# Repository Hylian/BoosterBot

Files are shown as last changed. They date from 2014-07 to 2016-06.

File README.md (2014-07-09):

BoosterBot
==========

A BoosterPack that turns your TI Launchpad into a fully functional robot!

The BoosterBot attaches underneath any 40-pin Launchpad to give it batteries, wheels, and access to a bunch of sensors; perfect for anyone who wants to get started with MSP430 and robotics, or just wants an easy to use robotics platform to build off of.

Features
--------
* Micro Metal Gearmotors from Pololu
* Powered by 3xAAA batteries
* Five QRE1113 Reflectance sensors for line following and maze solving
* Header for a Sharp IR distance sensor
* Header for a servo
* Compatible with other BoosterPacks, including the FuelTank battery BoosterPack

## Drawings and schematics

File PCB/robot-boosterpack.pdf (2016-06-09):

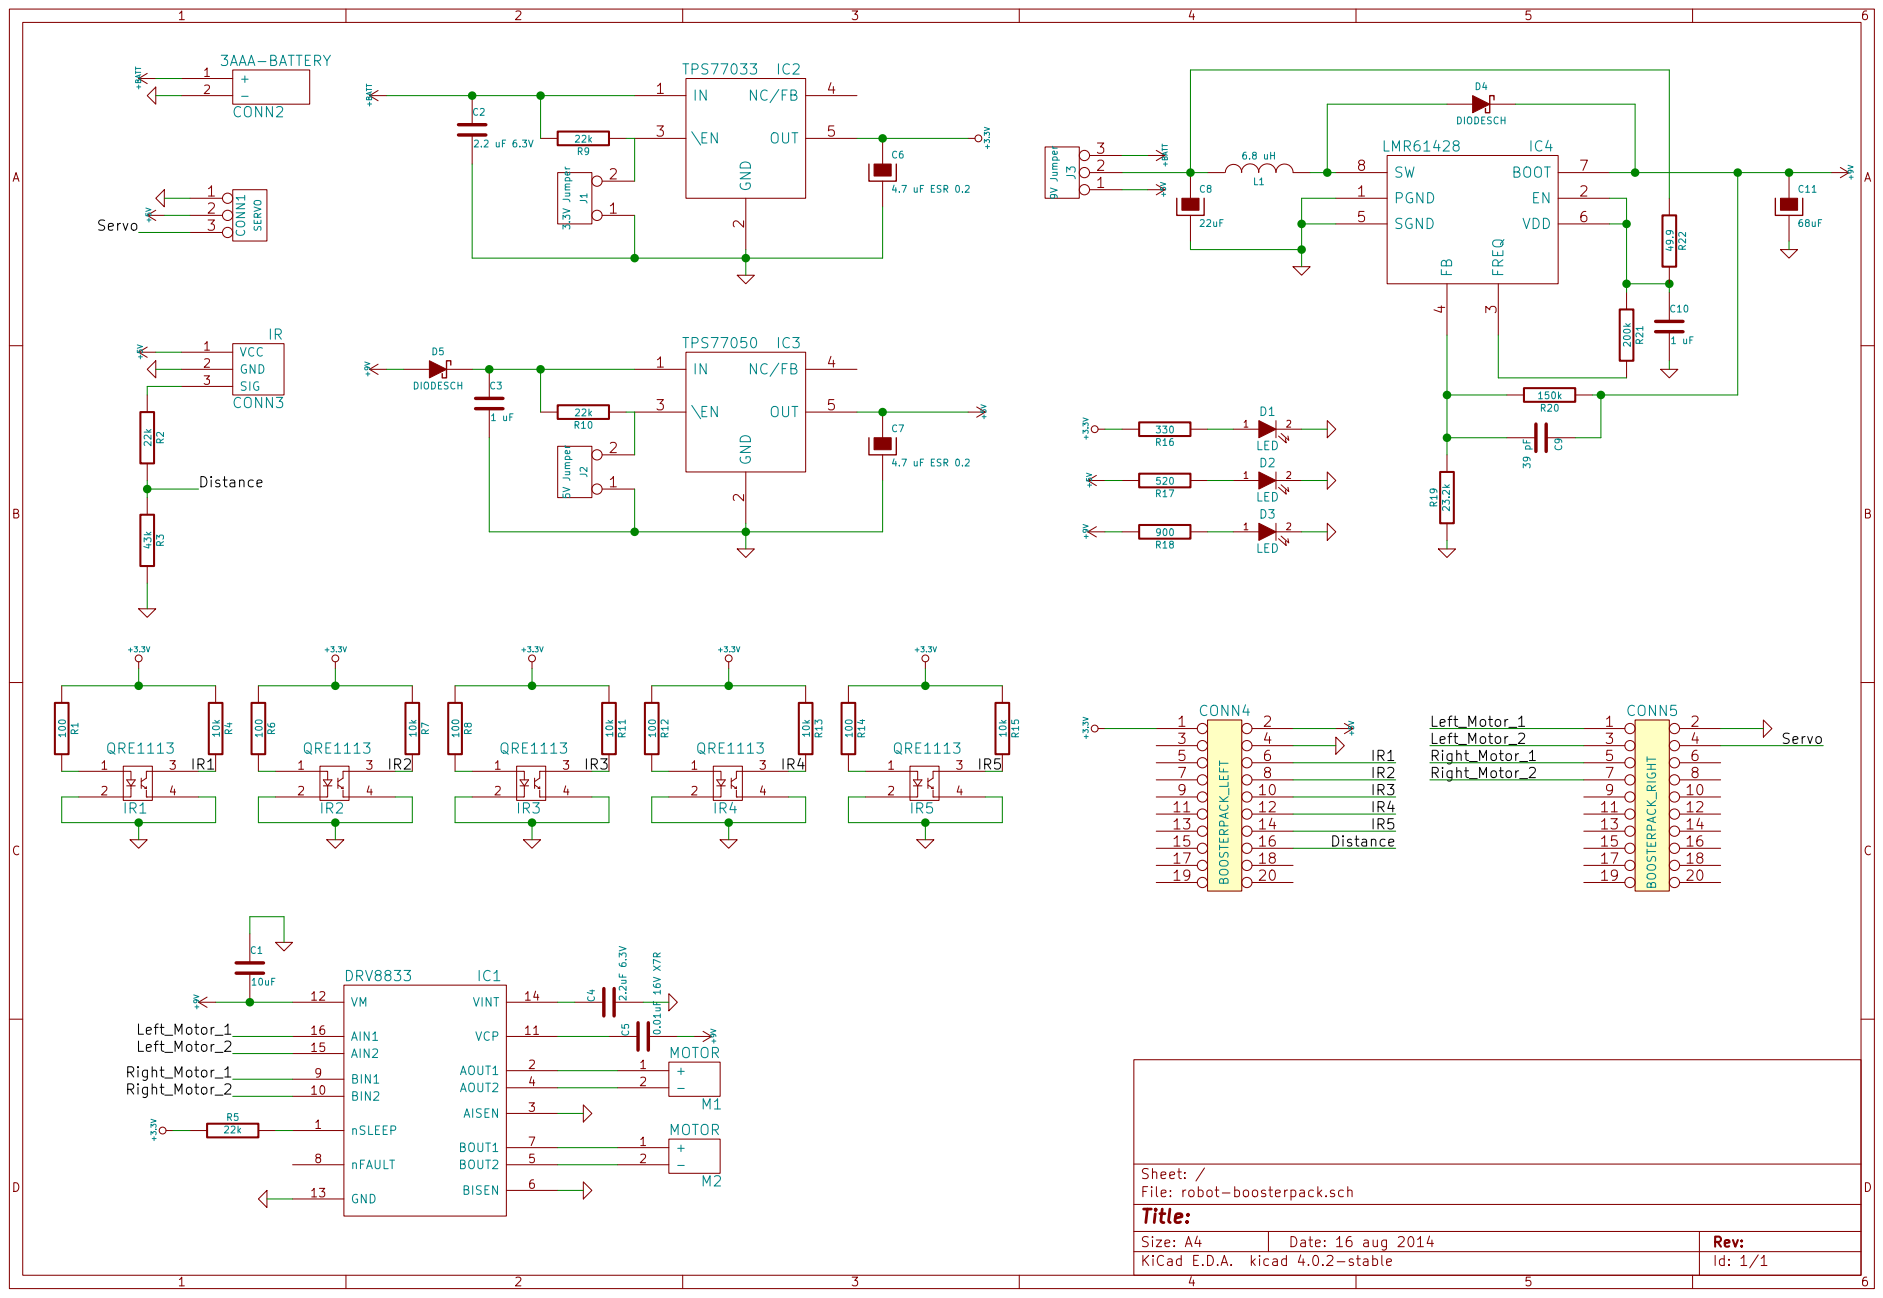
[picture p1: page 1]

4 SGND 5 VDD 6 BOOT 7 SW 8

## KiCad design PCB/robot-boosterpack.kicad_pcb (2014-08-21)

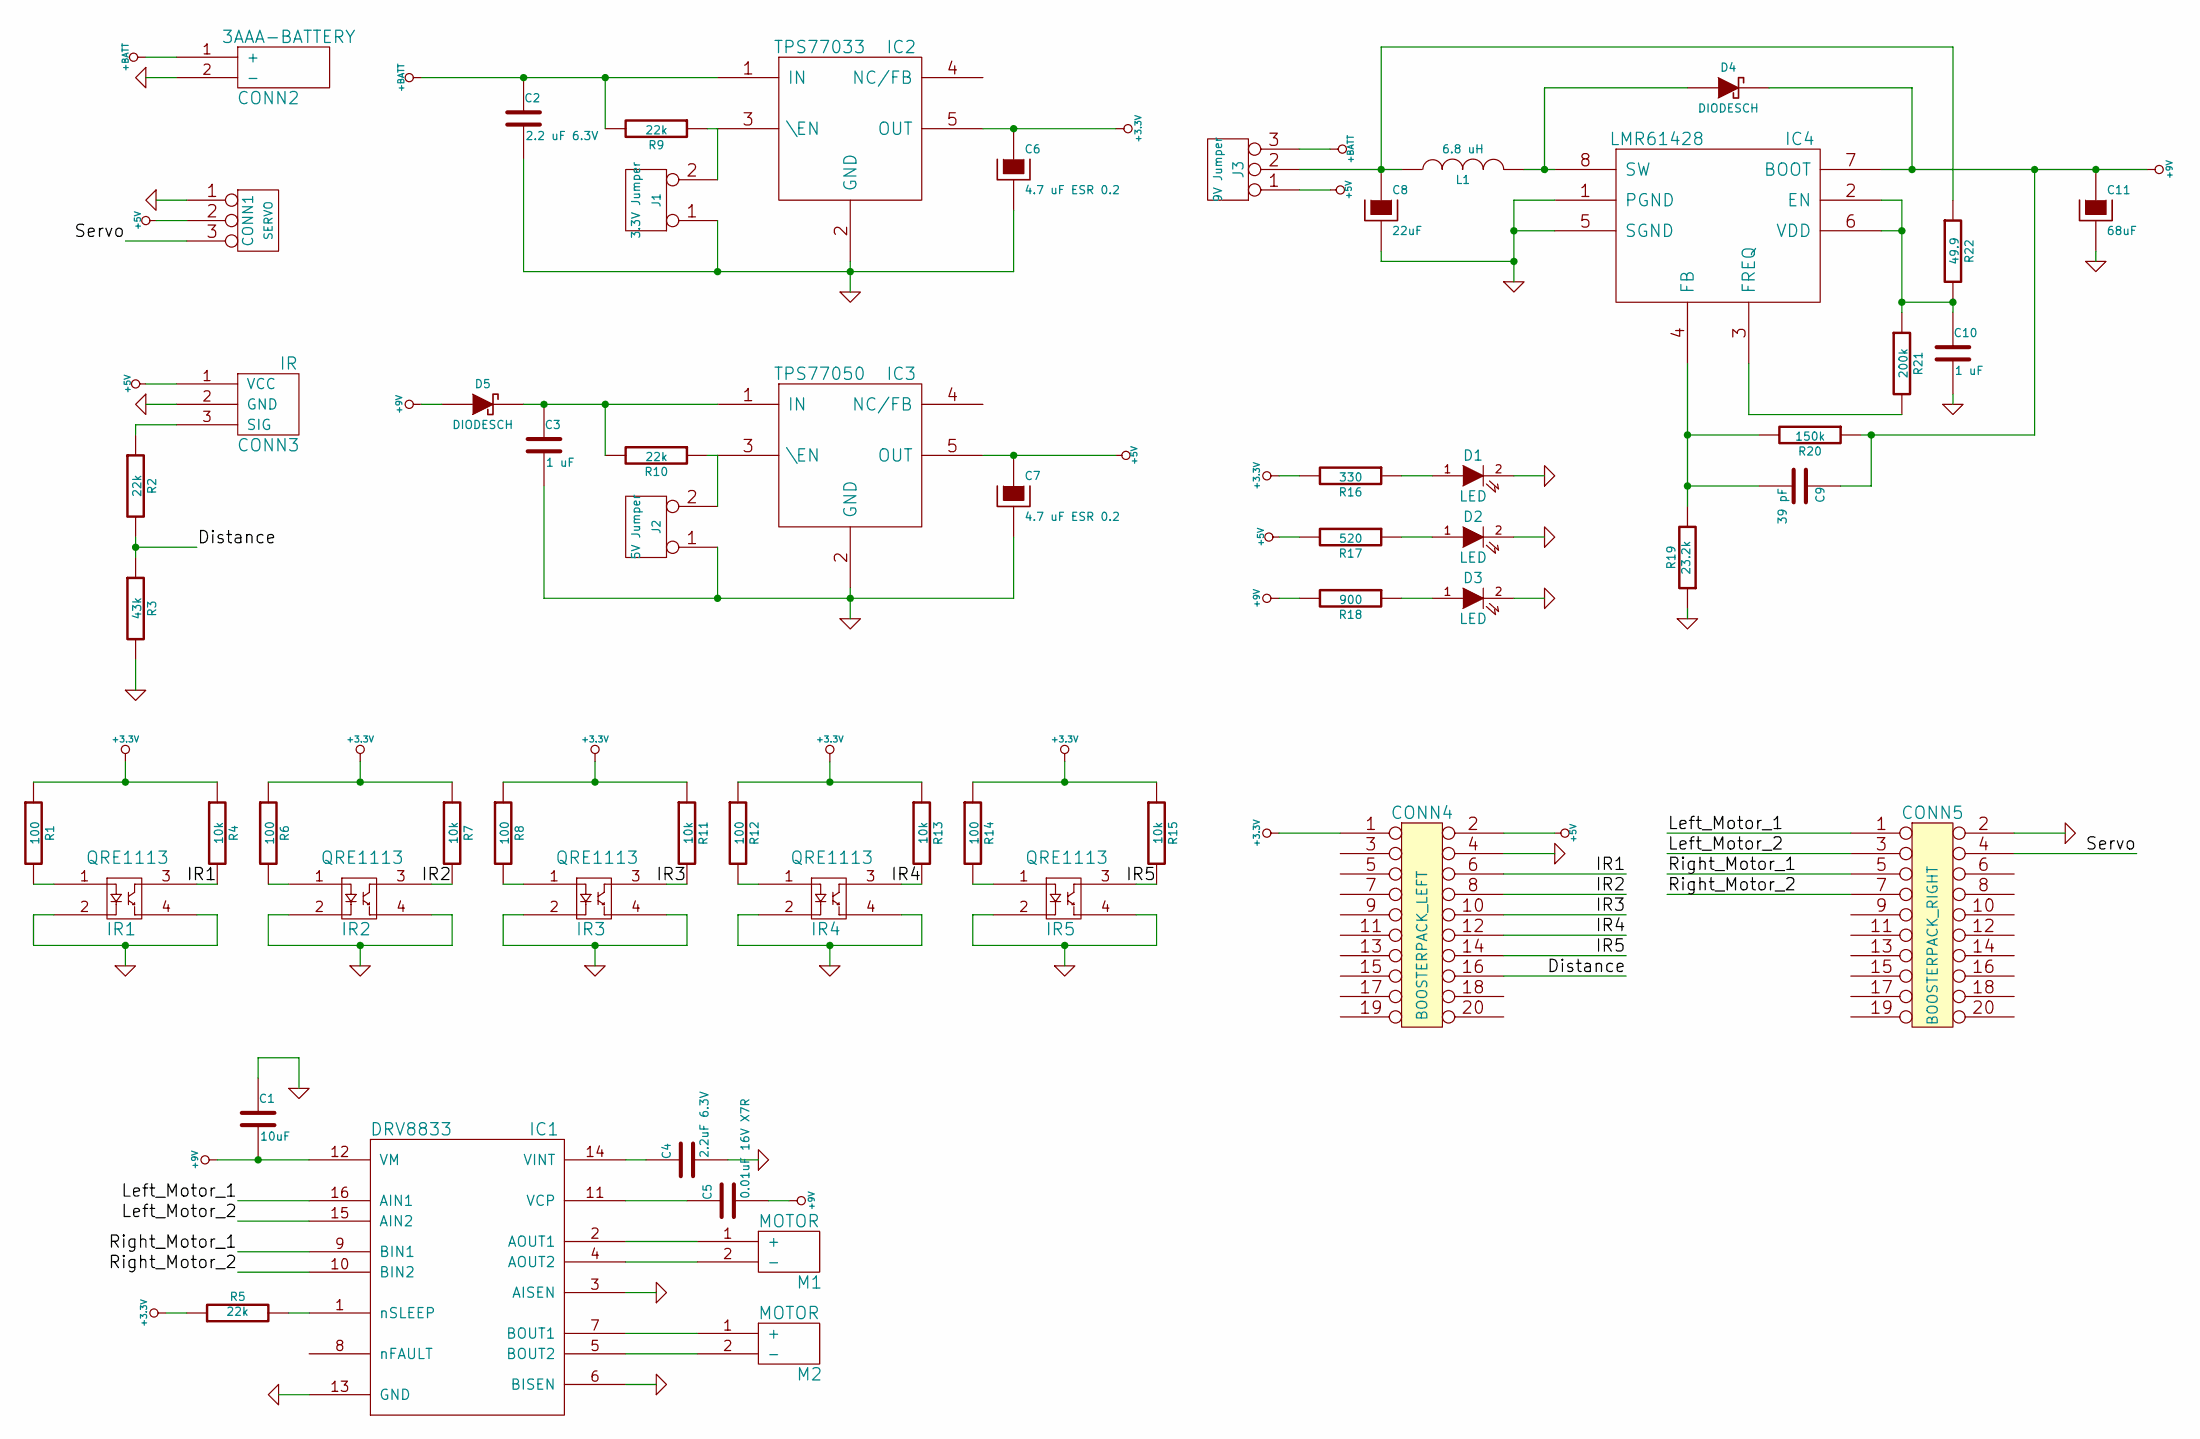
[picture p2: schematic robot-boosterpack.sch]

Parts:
C1: 10uF; Digikey # 311-1343-1-ND
C2: 2.2 uF 6.3V; Digikey # 587-1254-1-ND
C3, C10: 1 uF; Digikey # 587-1242-1-ND
C4: 2.2uF 6.3V; Digikey # 587-1254-1-ND
C5: 0.01uF 16V X7R; Digikey # 490-1512-1-ND
C6, C7: 4.7 uF ESR 0.2; Digikey # 478-1772-1-ND
C8: 22uF; Digikey # 399-3716-1-ND
C9: 39 pF
C11: 68uF; Digikey # 399-4698-1-ND
CONN1: SERVO; Digikey # 609-3461-ND
CONN2: 3AAA-BATTERY
CONN3: IR; Digikey # S5751-03-ND
CONN4: BOOSTERPACK_LEFT
CONN5: BOOSTERPACK_RIGHT
D1: LED; Digikey # 160-1448-1-ND
D2: LED; Digikey # 160-1447-1-ND
D3: LED; Digikey # 160-1647-1-ND
D4, D5: DIODESCH; Digikey # MBRS140T3GOSCT-ND
IC1: DRV8833
IC2: TPS77033
IC3: TPS77050
IC4: LMR61428
IR1, IR2, IR3, IR4, IR5: QRE1113
J1: 3.3V Jumper; Digikey # 3M9447-ND
J2: 5V Jumper; Digikey # 3M9447-ND
J3: 9V Jumper; Digikey # 609-3461-ND
L1: 6.8 uH; Digikey # SRN6045-100MCT-ND
M1, M2: MOTOR
R1, R6, R8, R12, R14: 100; Digikey # 311-100HRCT-ND
R2, R5, R9, R10: 22k; Digikey # P22KDBTR-ND
R3: 43k; Digikey # 311-43.0KHRCT-ND
R4, R7, R11, R13, R15: 10k; Digikey # 311-10KGRCT-ND
R16: 330; Digikey # 311-165HRCT-ND
R17: 520; Digikey # P261HCT-ND
R18: 900; Digikey # P453HCT-ND
R19: 23.2k; Digikey # 311-23.2KHRTR-ND
R20: 150k; Digikey # P150KDBCT-ND
R21: 200k; Digikey # P200KDBCT-ND
R22: 49.9; Digikey # P49.9HCT-ND

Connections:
+3.3V: C6.1, CONN4.1, IC2.5 (OUT), R1.1, R4.1, R5.1, R6.1, R7.1, R8.1, R11.1, R12.1, R13.1, R14.1, R15.1, R16.2
+5V: C7.1, CONN1.2 (PM), CONN3.1 (VCC), CONN4.2, IC3.5 (OUT), J3.1, R17.2
+9V: C1.2, C5.2, C9.1, C11.1, D4.2 (K), D5.1 (A), IC1.12 (VM), IC4.7 (BOOT), R18.2, R20.1
+BATT: C2.1, CONN2.1 (+), IC2.1 (IN), J3.3, R9.2
/Distance: CONN4.16, R2.2, R3.1
/IR1: CONN4.6, IR1.3, R4.2
/IR2: CONN4.8, IR2.3, R7.2
/IR3: CONN4.10, IR3.3, R11.2
/IR4: CONN4.12, IR4.3, R13.2
/IR5: CONN4.14, IR5.3, R15.2
/Left_Motor_1: CONN5.1, IC1.16 (AIN1)
/Left_Motor_2: CONN5.3, IC1.15 (AIN2)
/Right_Motor_1: CONN5.5, IC1.9 (BIN1)
/Right_Motor_2: CONN5.7, IC1.10 (BIN2)
/Servo: CONN1.3, CONN5.4
GND: C1.1, C2.2, C3.2, C4.2, C6.2, C7.2, C8.2, C10.2, C11.2, CONN1.1, CONN2.2 (-), CONN3.2 (GND), CONN4.4, CONN5.2, D1.2 (K), D2.2 (K), D3.2 (K), IC1.3 (AISEN), IC1.6 (BISEN), IC1.13 (GND), IC2.2 (GND), IC3.2 (GND), IC4.1 (PGND), IC4.5 (SGND), IR1.2, IR1.4, IR2.2, IR2.4, IR3.2, IR3.4, IR4.2, IR4.4, IR5.2, IR5.4, J1.1, J2.1, R3.2, R19.1
unnamed: C9.2, IC4.4 (FB), R19.2, R20.2
unnamed: IC4.3 (FREQ), R21.2
unnamed: IR4.1, R12.2
unnamed: C10.1, IC4.2 (EN), IC4.6 (VDD), R21.1, R22.2
unnamed: IR3.1, R8.2
unnamed: IR2.1, R6.2
unnamed: C4.1, IC1.14 (VINT)
unnamed: C5.1, IC1.11 (VCP)
unnamed: IC1.1 (nSLEEP), R5.2
unnamed: IR1.1, R1.2
unnamed: CONN3.3 (SIG), R2.1
unnamed: D4.1 (A), IC4.8 (SW), L1.2
unnamed: D3.1 (A), R18.1
unnamed: D2.1 (A), R17.1
unnamed: D1.1 (A), R16.1
unnamed: C8.1, J3.2 (PM), L1.1, R22.1
unnamed: IC3.3 (\EN), J2.2 (PM), R10.1
unnamed: IR5.1, R14.2
unnamed: IC2.3 (\EN), J1.2 (PM), R9.1
unnamed: IC1.7 (BOUT1), M2.1 (+)
unnamed: IC1.5 (BOUT2), M2.2 (-)
unnamed: IC1.4 (AOUT2), M1.2 (-)
unnamed: IC1.2 (AOUT1), M1.1 (+)
unnamed: C3.1, D5.2 (K), IC3.1 (IN), R10.2

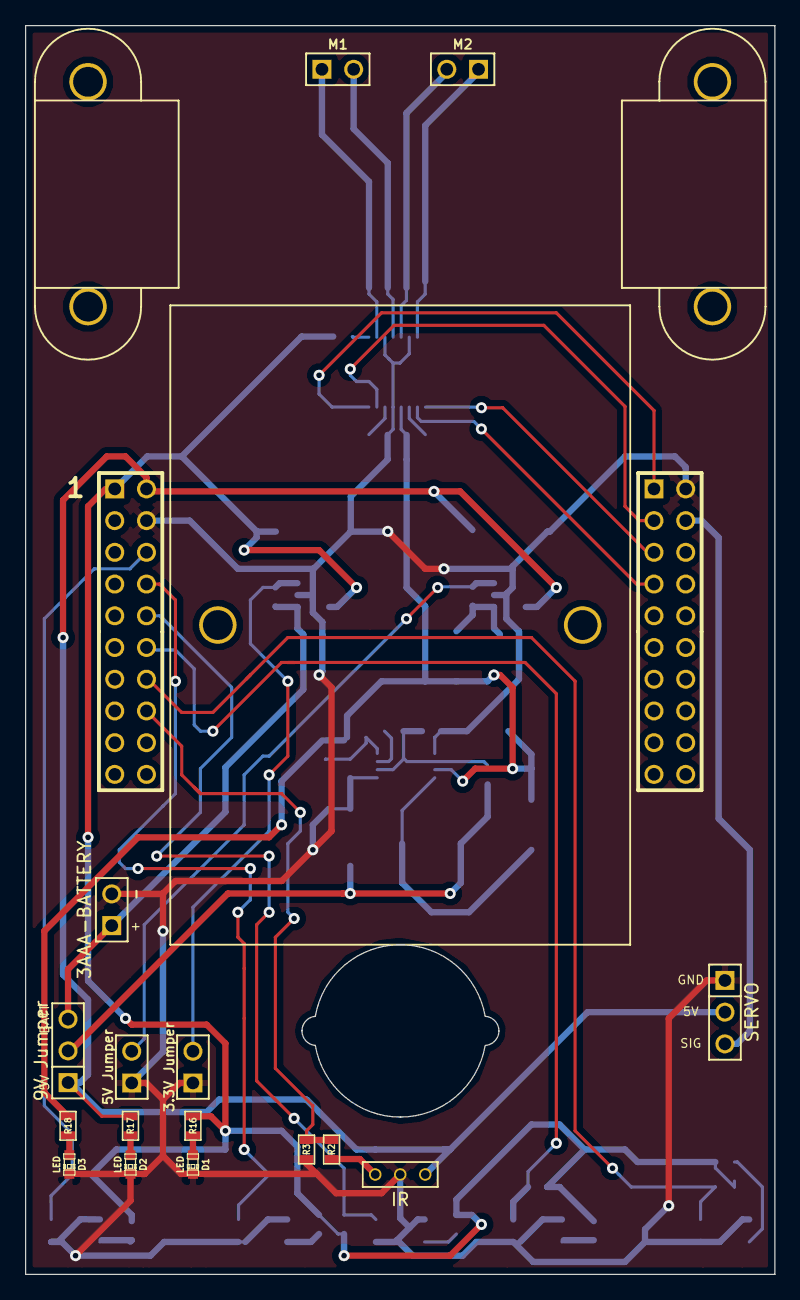
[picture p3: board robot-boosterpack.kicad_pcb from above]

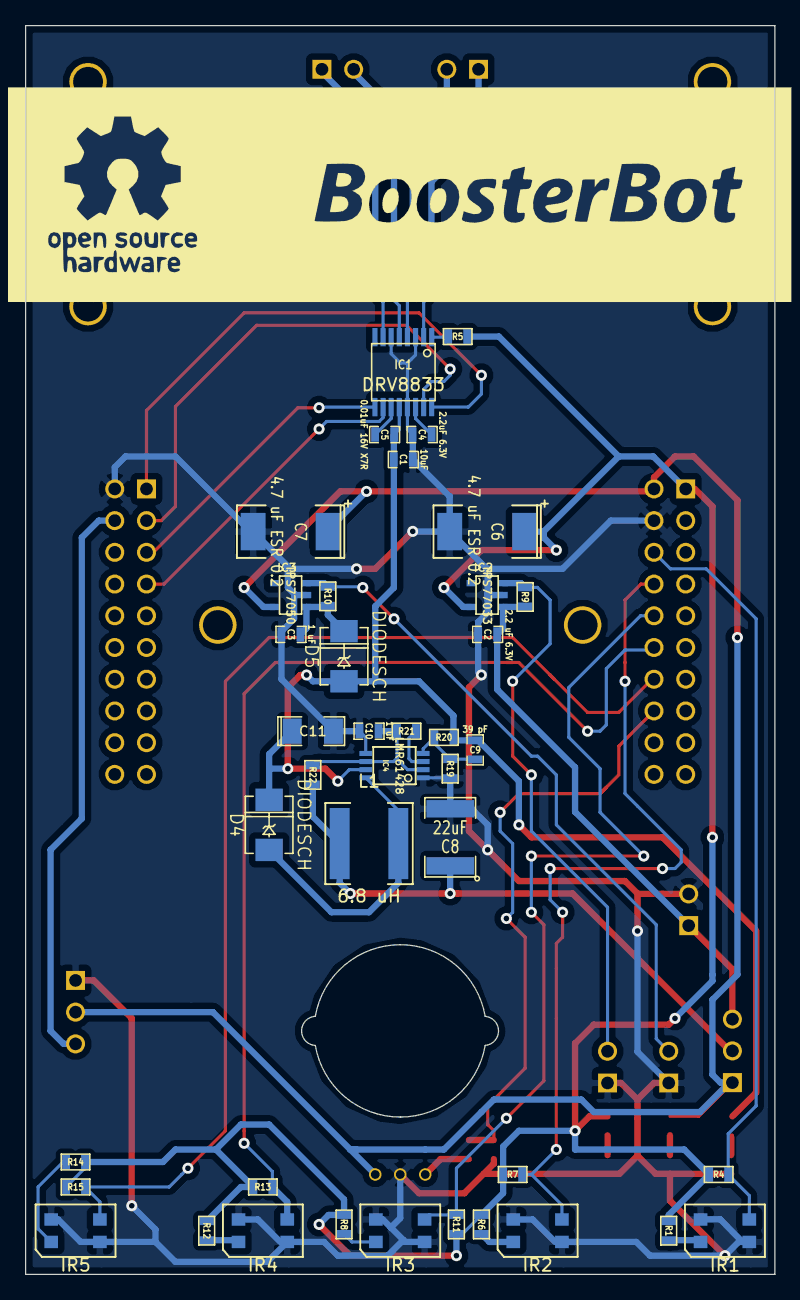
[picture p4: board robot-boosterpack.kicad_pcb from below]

Board: 2 copper layers, 60.0 x 100.0 mm, 61 parts (40 on the bottom side), 40 nets.

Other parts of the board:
BATTERY: P***; 3xAAA
GEARMOTOR: P***; 1pin
GEARMOTOR#2: P***; 1pin

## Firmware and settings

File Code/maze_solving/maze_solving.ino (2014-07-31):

#include "Motor.h"
#include "PID_v1.h"

double Setpoint, Input, Output;

bool sensorBool[5];
bool prevLeft, prevRight;
uint32_t threshold;

const uint8_t sensorPin[5] = {23, 24, 25, 26, 27};

const uint8_t baseSpeed = 100;
const uint8_t turnSpeed = 30;

PID linePID(&Input, &Output, &Setpoint, 40, 5, 1, DIRECT);

Motor leftMotor(37, 38, true);
Motor rightMotor(40, 39, true);

enum mazeState {STOP, FOLLOW, TURN_LEFT, TURN_RIGHT, DONE};

void calibrate()
{
	threshold = 0;
	for(char i = 0; i < 5; i++)
		threshold += analogRead(sensorPin[i]);
	threshold /= 5;
	threshold += 10;
        Serial.print("Threshold set: ");
        Serial.println(threshold);
}

void readSensors()
{
	for(char i = 0; i < 5; i++)
		sensorBool[i] = (analogRead(sensorPin[i]) < threshold);
}

void calculateError()
{
	if(sensorBool[1] && !sensorBool[2] && !sensorBool[3])
		Input = 2.0;
	else if(sensorBool[1] && sensorBool[2] && !sensorBool[3])
		Input = 1.0;
	else if(	(sensorBool[1] && sensorBool[2] && sensorBool[3]) ||
				(!sensorBool[1] && sensorBool[2] && !sensorBool[3]) 
	  		)
	  	Input = 0.0;
	else if(!sensorBool[1] && sensorBool[2] && sensorBool[3])
		Input = -1.0;
	else if(!sensorBool[1] && !sensorBool[2] && sensorBool[3])
		Input = -2.0;
	else
		Input = 0.0;

        Serial.print("Error: ");
        Serial.println(Input);
}

void setup()
{
        Serial.begin(9600);
        mazeState state = STOP;
	Input = 0;
	Setpoint = 0;
	linePID.SetMode(MANUAL);
	linePID.SetOutputLimits(-100, 100);
        leftMotor.setVelocity(speed);
	rightMotor.setVelocity(speed);  
        calibrate();
}

void loop()
{
	switch(state)
	{
		case STOP:
			linePID.SetMode(MANUAL);
			leftMotor.setSpeed(0);
			rightMotor.setSpeed(0);
			break;

		case FOLLOW:
			linePID.SetMode(AUTOMATIC);
			while(!sensorBool[0] || !sensorBool[4] || (!sensorBool[1]&&!sensorBool[2]&&!sensorBool[3]))
			{
				readSensors();
				calculateError();
				linePID.Compute();
				leftMotor.setSpeed(baseSpeed + Output);
				rightMotor.setSpeed(baseSpeed - Output);
			}
			prevLeft = sensorBool[0];
			prevRight = sensorBool[4];
			delay(400);
			readSensors();
			if(sensorBool[0]&&sensorBool[1]&&sensorBool[2]&&sensorBool[3]&&sensorBool[4])
				state = DONE;
			else if(prevLeft)
				state = TURN_LEFT;
			else
				state = TURN_RIGHT;
			break;

		case TURN_LEFT:
			linePID.SetMode(MANUAL);
			leftMotor.setSpeed(baseSpeed - turnSpeed);
			rightMotor.setSpeed(baseSpeed + turnSpeed);
			do
			{
				readSensors();
			}
			while(sensorBool[2]);
			do
			{
				readSensors();
			}
			while(!sensorBool[2]);
			state = FOLLOW;
			break;

		case TURN_RIGHT:
			linePID.SetMode(MANUAL);
			leftMotor.setSpeed(baseSpeed + turnSpeed);
			rightMotor.setSpeed(baseSpeed - turnSpeed);
			do
			{
				readSensors();
			}
			while(sensorBool[2]);
			do
			{
				readSensors();
			}
			while(!sensorBool[2]);
			state = FOLLOW;
			break;

		case DONE:
			linePID.SetMode(MANUAL);
			leftMotor.setSpeed(0);
			leftMotor.setSpeed(0);
			for(;;) {}
	}


	delay(50);
}

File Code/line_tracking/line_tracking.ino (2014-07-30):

#include "Motor.h"
#include "PID_v1.h"
#include "RunningAverage.h"

double Setpoint, prevInput, Input, Output;

bool sensorBool[5];
bool lostInput;
uint32_t threshold[5];
uint32_t maxValues[5], minValues[5], avgValues[5];
uint32_t tempValue;

const uint8_t sensorPin[5] = {23, 24, 25, 26, 27};

const uint8_t speed = 45;

PID linePID(&Input, &Output, &Setpoint, 5, 0, 0, DIRECT);

RunningAverage RA0(30);
RunningAverage RA1(30);
RunningAverage RA2(30);
RunningAverage RA3(30);
RunningAverage RA4(30);

Motor leftMotor(37, 38, true);
Motor rightMotor(40, 39, true);

void calibrate()
{
        while(digitalRead(P1_1)){}
        while(!digitalRead(P1_1)){}
        
        for(char i = 0; i < 5; i++)
        {
          minValues[i] = 0;
          maxValues[i] = 0;
        }        
        
        delay(500);
        
        Serial.println("Starting calibration");
        
        for(char i = 0; i < 5; i++)
        {
          minValues[i] = analogRead(sensorPin[i]);
          maxValues[i] = minValues[i];
        }
        
        while(digitalRead(P1_1))
        {
          for(char i = 0; i < 5; i++)
          {
            tempValue = analogRead(sensorPin[i]);
            if(tempValue < minValues[i])
              minValues[i] = tempValue;
            if(tempValue > maxValues[i])
              maxValues[i] = tempValue;
            Serial.print(tempValue);
            Serial.print(" ");
          }
          Serial.println();
        }
        
        for(char i = 0; i < 5; i++)
        {
          avgValues[i] = (2*minValues[i] + 3*maxValues[i])/5;
        }
        
        Serial.println("Calibration complete!");
            
        for(char i = 0; i < 5; i++)
          {
          Serial.println(avgValues[i]);        
          }
        /**
        for(char i = 0; i < 5; i++)
		threshold[i] = 0;
        for(char j = 0; j < 5; j++)
        {
            for(char i = 0; i < 5; i++)
		threshold[i] += analogRead(sensorPin[i]);
        }
        for(char i = 0; i < 5; i++)
        {
                threshold[i] /= 5;
                threshold[i] -= 400;
        }
        
        threshold[1] -= 500;
        threshold[2] -= 500;
	
        Serial.print("Threshold set: ");
        Serial.print(threshold[0]);
        Serial.print(" ");
        Serial.print(threshold[1]);
        Serial.print(" ");
        Serial.print(threshold[2]);
        Serial.print(" ");
        Serial.print(threshold[3]);
        Serial.print(" ");
        Serial.println(threshold[4]);
        
        */

}

void calibrate2()
{
  while(digitalRead(P1_1)){}
  while(!digitalRead(P1_1)){}
  
  Serial.println("Starting white calibration...");
  
  RA0.clear();
  RA1.clear();
  RA2.clear();
  RA3.clear();
  RA4.clear();
  
  while(digitalRead(P1_1))
  {
    RA0.addValue(analogRead(sensorPin[0]));
    RA1.addValue(analogRead(sensorPin[1]));
    RA2.addValue(analogRead(sensorPin[2]));
    RA3.addValue(analogRead(sensorPin[3]));
    RA4.addValue(analogRead(sensorPin[4]));
    Serial.println("averaging whites...");
  }

  minValues[0] = RA0.getAverage();
  minValues[1] = RA1.getAverage();
  minValues[2] = RA2.getAverage();
  minValues[3] = RA3.getAverage();
  minValues[4] = RA4.getAverage();
  
  while(!digitalRead(P1_1));
  
  delay(100);

  Serial.println("Starting black calibration...");

  RA0.clear();
  RA1.clear();
  RA2.clear();
  RA3.clear();
  RA4.clear();
  
  while(digitalRead(P1_1))
  {
    RA0.addValue(analogRead(sensorPin[0]));
    RA1.addValue(analogRead(sensorPin[1]));
    RA2.addValue(analogRead(sensorPin[2]));
    RA3.addValue(analogRead(sensorPin[3]));
    RA4.addValue(analogRead(sensorPin[4]));
        Serial.println("averaging blacks...");
  }

  maxValues[0] = RA0.getAverage();
  maxValues[1] = RA1.getAverage();
  maxValues[2] = RA2.getAverage();
  maxValues[3] = RA3.getAverage();
  maxValues[4] = RA4.getAverage();
  
  avgValues[0] = (2 * minValues[0] + 3 * maxValues[0])/5;
  avgValues[1] = (2 * minValues[1] + 3 * maxValues[1])/5;
  avgValues[2] = (2 * minValues[2] + 3 * maxValues[2])/5;
  avgValues[3] = (2 * minValues[3] + 3 * maxValues[3])/5;
  avgValues[4] = (2 * minValues[4] + 3 * maxValues[4])/5;
  
          Serial.println("Calibration complete!");
            
        for(char i = 0; i < 5; i++)
          {
          Serial.println(avgValues[i]);        
          }
}  
  

void readSensors()
{
  for(char i = 0; i < 5; i++)
  {
    sensorBool[i] = analogRead(sensorPin[i]) >   avgValues[i];
  }
}

void calculateError()
{
	if(sensorBool[1] && !sensorBool[2] && !sensorBool[3])
		Input = 2.0;
	else if(sensorBool[1] && sensorBool[2] && !sensorBool[3])
		Input = 1.0;
	else if(	(sensorBool[1] && sensorBool[2] && sensorBool[3]) ||
			(!sensorBool[1] && sensorBool[2] && !sensorBool[3]) 
	  		)
	  	Input = 0.0;
	else if(!sensorBool[1] && sensorBool[2] && sensorBool[3])
		Input = -1.0;
	else if(!sensorBool[1] && !sensorBool[2] && sensorBool[3])
		Input = -2.0;
	else if(!lostInput)
        {
          Input = -prevInput;
          lostInput = true;
          return;
        }
        else
          return;
        lostInput = false;
                 
        prevInput = Input;
        //Serial.print("Error: ");
        //Serial.println(Input);
}

void setup()
{
        pinMode(P1_1, INPUT_PULLUP);
        Serial.begin(9600);
	Input = 0;
        prevInput = 0;
	Setpoint = 0;
        leftMotor.setVelocity(0);
	rightMotor.setVelocity(0);
        calibrate();
	linePID.SetMode(AUTOMATIC);
	linePID.SetOutputLimits(-100, 100);
        leftMotor.setVelocity(speed);
	rightMotor.setVelocity(speed);

}

void loop()
{
	readSensors();
	calculateError();
	linePID.Compute();
	//leftMotor.setVelocity(speed - Output);
	//rightMotor.setVelocity(speed + Output);
	leftMotor.setVelocity(0);
	rightMotor.setVelocity(0);
        //Serial.print("Output: ");
        //Serial.println(Output);
        Serial.print("Reading: ");
        Serial.print(sensorBool[0]);
        Serial.print(" ");
        Serial.print(sensorBool[1]);
        Serial.print(" ");
        Serial.print(sensorBool[2]);
        Serial.print(" ");
        Serial.print(sensorBool[3]);
        Serial.print(" ");
        Serial.println(sensorBool[4]);
        //Serial.print("Raw Input: ");
        //Serial.print(analogRead(sensorPin[1]));
        //Serial.print(" ");
        //Serial.print(analogRead(sensorPin[2]));
        //Serial.print(" ");
        //Serial.println(analogRead(sensorPin[3]));
}

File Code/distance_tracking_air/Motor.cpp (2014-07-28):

/*
 * Motor.cpp
 * Controls a single motor connected to a DRV8833 motor driver via PWM.
 * Created by Edward Shin, 11 July 2014.
 */

#include "Energia.h"
#include "Motor.h"


Motor::Motor(uint16_t forwardPin, uint16_t reversePin, bool hardBrake)
{
	_forwardPin = forwardPin;
	_reversePin = reversePin;
	_hardBrake = hardBrake;
	_pin = _forwardPin;
	_speed = 0;
	_direction = FORWARD;

	pinMode(_forwardPin, OUTPUT);
	pinMode(_reversePin, OUTPUT);
}

void Motor::setSpeed(uint8_t speed)
{
	_speed = speed;
	analogWrite(_pin, _speed);

	if(_speed = 0)
	{
		if(_pin == _forwardPin)
			analogWrite(_reversePin, _hardBrake ? 255 : 0);
		else
			analogWrite(_forwardPin, _hardBrake ? 255 : 0);
	}

	return;
}

void Motor::setDirection(motor_directions_t direction)
{
	_direction = direction;
	_pin = (_direction == FORWARD) ? _forwardPin : _reversePin;
	analogWrite(_pin, _speed);

	if(_pin == _forwardPin)
		analogWrite(_reversePin, 0);
	else
		analogWrite(_forwardPin, 0);

	return;
}

void Motor::setHardBrake(bool hardBrake)
{
	if(_hardBrake != hardBrake)
	{
		if(_pin == _forwardPin)
			analogWrite(_reversePin, hardBrake ? 255 : 0);
		else
			analogWrite(_forwardPin, hardBrake ? 255 : 0);
	}

	_hardBrake = hardBrake;

	return;
}

void Motor::setVelocity(int16_t velocity)
{
	if(!(-255 <= velocity && velocity <= 255))
		return;

	_direction = (velocity >= 0) ? FORWARD : REVERSE;
	setDirection(_direction);

	_speed = abs(velocity);
	setSpeed(_speed);

	return;
}

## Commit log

2014-06-18 Created KiCAD Schematic
    [robot-boosterpack.sch]
2014-06-22 added libraries for motor driver, motor, and IR
    [robot-boosterpack.sch]
2014-06-22 added reflectance sensor
    [robot-boosterpack.sch]
2014-06-22 added battery holder
    [robot-boosterpack.sch]
2014-06-23 fixed grid alignment on reflectance sensor
    [robot-boosterpack.sch]
2014-06-23 created reflectance sensor circuit
    [robot-boosterpack.sch]
2014-06-23 created motor controller circuit
    [robot-boosterpack.sch]
2014-06-23 Misc changes
    [robot-boosterpack.sch]
2014-06-23 added 3.3V regulator part
    [robot-boosterpack.sch]
2014-06-23 created 3.3V regulator circuit
    [robot-boosterpack.sch]
2014-06-23 created 12V regulator component
    [$robot-boosterpack.sch]
2014-06-23 created 10V regulator schematic
    [robot-boosterpack.sch]
2014-06-24 added 5V regulator
2014-06-24 added 5V regulator circuit
    [robot-boosterpack.sch]
2014-06-24 updated 5V regulator circuit
    [robot-boosterpack.sch]
2014-06-24 updated 5V regulator capacitor values
    [robot-boosterpack.sch]
2014-06-24 added servo connectors
    [robot-boosterpack.sch]
2014-06-24 created boosterpack connections
    [robot-boosterpack.sch]
2014-06-24 updated servo connector label
    [robot-boosterpack.sch]
2014-06-24 added regulator jumpers
    [robot-boosterpack.sch]
2014-06-25 annotated schematic
    [robot-boosterpack.sch]
2014-06-25 changed output voltage of switching regulator to 9V from 10V
    [robot-boosterpack.sch]
2014-06-25 changed switching regulator from bootstrap to non-bootstrapping mode
    [robot-boosterpack.sch]
2014-06-25 re-annotated schematic
2014-06-25 replaced 10V labels with 9V labels
    [robot-boosterpack.sch]
2014-06-25 added damping resistor to regulator circuit
    [robot-boosterpack.sch]
2014-06-26 generated netlist
    [robot-boosterpack.sch]
2014-06-27 added regulator status LEDs
    [$robot-boosterpack.sch, robot-boosterpack.sch]
2014-06-27 generated netlist and BOM
2014-06-27 added part number for IR distance sensor connector
    [robot-boosterpack.sch]
2014-06-27 added part numbers for LEDs
    [robot-boosterpack.sch]
2014-06-29 finished footprint association, added custom footprints
2014-06-29 created pcb file
    [robot-boosterpack.kicad_pcb]
2014-06-29 added pcb outline
    [robot-boosterpack.kicad_pcb]
2014-06-30 organized pcb components
    [robot-boosterpack.kicad_pcb]
2014-07-01 added motor mount drill holes
    [robot-boosterpack.kicad_pcb]
2014-07-02 made pcb edges align to 10mm grid
    [robot-boosterpack.kicad_pcb]
2014-07-02 centered LP headers
    [robot-boosterpack.kicad_pcb]
2014-07-02 fixed motor mount orientation
    [robot-boosterpack.kicad_pcb]
2014-07-02 modified reflectance sensor module and placement
    [robot-boosterpack.kicad_pcb]
2014-07-02 fixed resistor placement for reflectance sensors
    [robot-boosterpack.kicad_pcb]
2014-07-02 spaced out reflectance sensors and made room for distance sensor
    [robot-boosterpack.kicad_pcb]
2014-07-02 placed LP headers in their proper position
    [robot-boosterpack.kicad_pcb]
2014-07-02 reoriented LEDs so that they go beyond the LP pcb
    [robot-boosterpack.kicad_pcb]
2014-07-02 spaced out the LEDs some more for silkscreen room
    [robot-boosterpack.kicad_pcb]
2014-07-02 lengthened board to make room for distance sensor
    [robot-boosterpack.kicad_pcb]
2014-07-02 added motor outline
    [robot-boosterpack.kicad_pcb]
2014-07-02 added battery drill module
    [robot-boosterpack.kicad_pcb]
2014-07-02 moved motor driver around to fit battery
    [robot-boosterpack.kicad_pcb]
2014-07-02 reoriented motor driver
    [robot-boosterpack.kicad_pcb]
2014-07-03 replaced inductor with smaller part
    [robot-boosterpack.kicad_pcb]
2014-07-03 added pololu 3/8" caster
    [robot-boosterpack.kicad_pcb]
2014-07-03 polished up silk
    [robot-boosterpack.kicad_pcb]
2014-07-03 moved motor connectors so silk is visible
    [robot-boosterpack.kicad_pcb]
2014-07-03 brought invisible pololu labels inside drill
    [robot-boosterpack.kicad_pcb]
2014-07-03 ir silk label
    [robot-boosterpack.kicad_pcb]
2014-07-03 fixed up more silk
    [robot-boosterpack.kicad_pcb]
2014-07-03 misc silk
    [robot-boosterpack.kicad_pcb]
2014-07-05 moved battery connector
    [robot-boosterpack.kicad_pcb]
2014-07-07 initial bad routing
    [robot-boosterpack.kicad_pcb]
2014-07-07 finished basic routing, expanded trace width
    [robot-boosterpack.kicad_pcb]
2014-07-07 fixed IR sensor being backwards
    [robot-boosterpack.kicad_pcb]
2014-07-07 added ground planes
    [robot-boosterpack.kicad_pcb]
2014-07-08 logo and gerbers to send to fab
    [robot-boosterpack.kicad_pcb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]
2014-07-11 initial motor driver library
2014-07-11 removed extra motor library files
2014-07-27 Fixes to motor lib
2014-07-28 Fixed motor library
2014-07-28 Added PID library
2014-07-30 tuned PID
2014-07-30 working basic distance sensor transmit/receive using AIR
2014-08-19 Rev 1.1
    [robot-boosterpack.kicad_pcb, robot-boosterpack.sch]
2014-08-21 Fixes for unupdated ground plane!
    [robot-boosterpack.kicad_pcb]
